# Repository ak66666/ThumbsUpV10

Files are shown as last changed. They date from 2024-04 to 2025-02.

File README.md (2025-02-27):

# ThumbsUp! v10 RP2040 Kailh Choc

Multilevel 44/46 Key Contoured Keyboard.
2- or 3-key Thumb Cluster.

* RP2040 is soldered on the board itself.
* Supports ProGlide Cirque touchpad.
* Hot swap sockets for switches.
* USB-C connector.
* Compact key spacing (18x17), large MX-size caps won't fit.
* Some keys on the lower PCB are tucked under the middle board to bring the index and middle fingers closer. That limits the choice of the key caps even more, only low profile would fit.

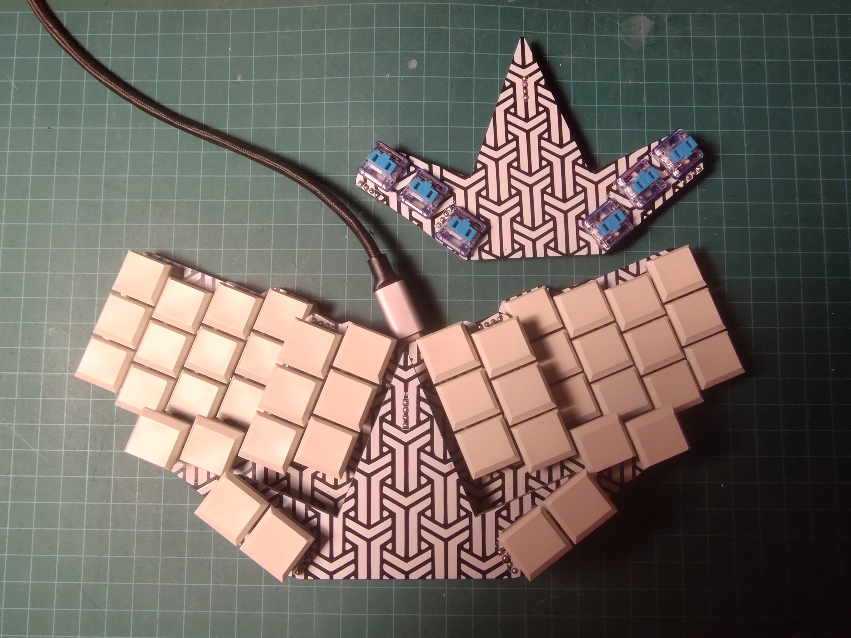
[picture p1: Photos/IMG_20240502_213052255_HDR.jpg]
Main view

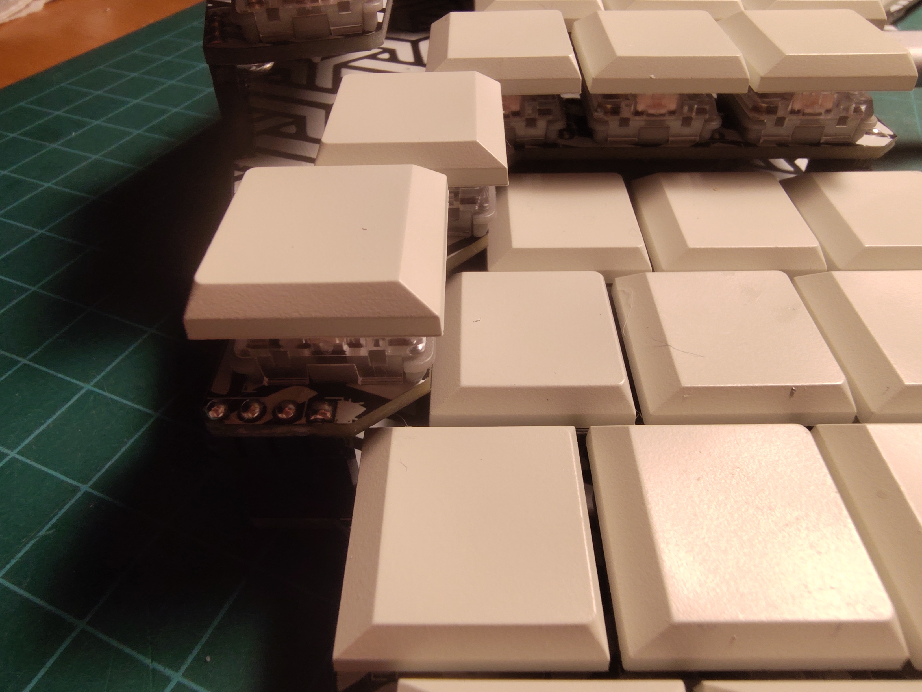
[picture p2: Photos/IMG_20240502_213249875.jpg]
Some keys are tucked under the middle PCB


Other pictures in Photos folder.

# Firmware

Please refer to this article:
https://thumbsupkeyboards.blogspot.com/2024/02/source-files-and-default-firmware.html

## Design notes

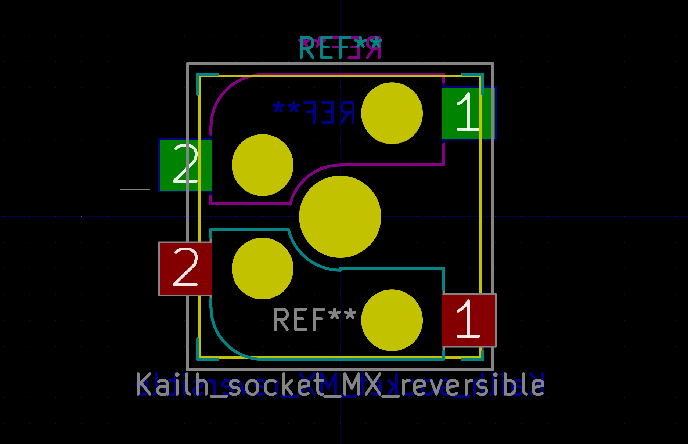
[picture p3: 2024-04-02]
keyswitches.pretty-master/images/Kailh_socket_MX_reversible_platemount.png

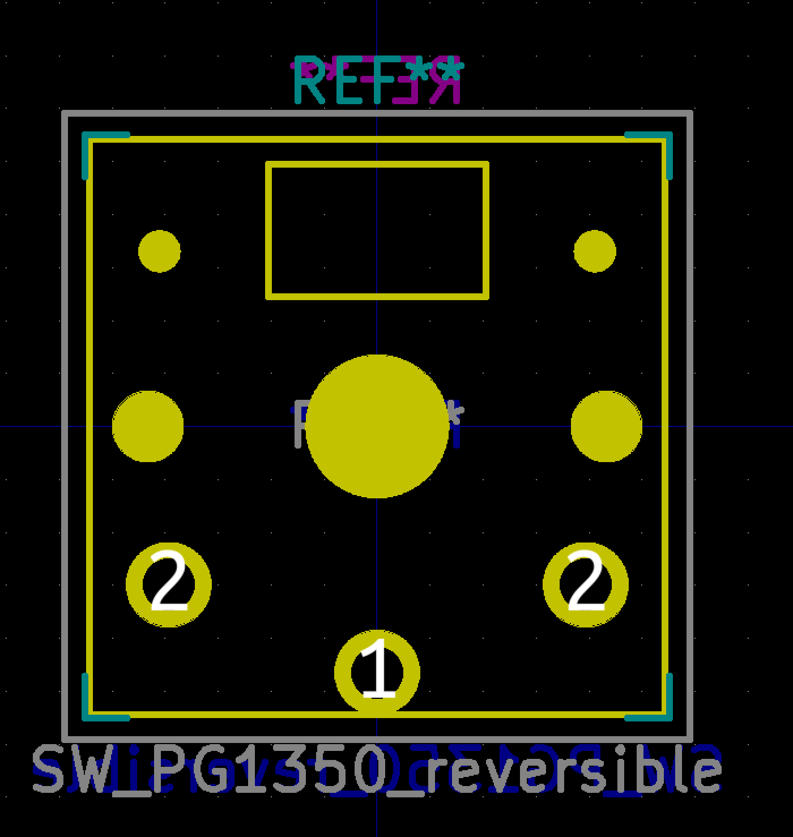
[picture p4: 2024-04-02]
keyswitches.pretty-master/images/SW_PG1350_reversible.png

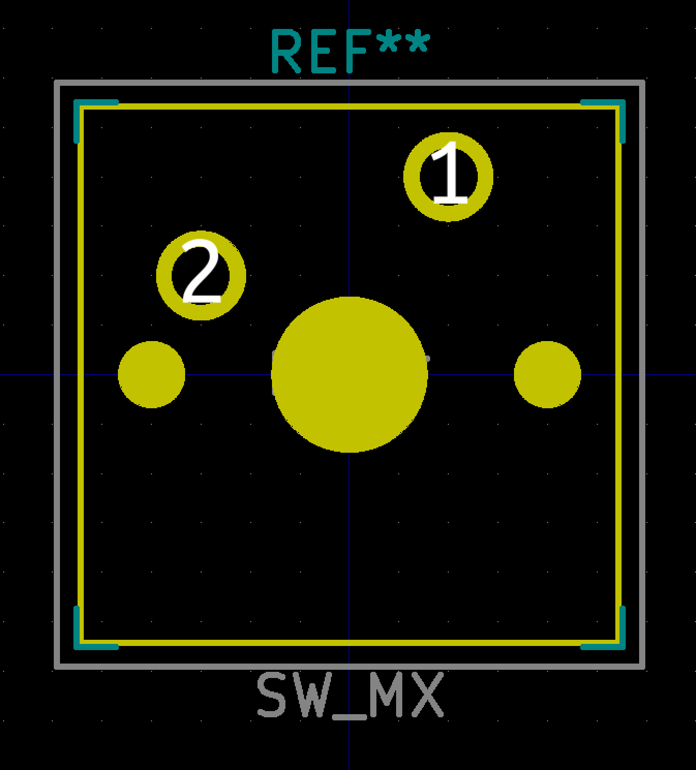
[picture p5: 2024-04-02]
keyswitches.pretty-master/images/SW_MX.png

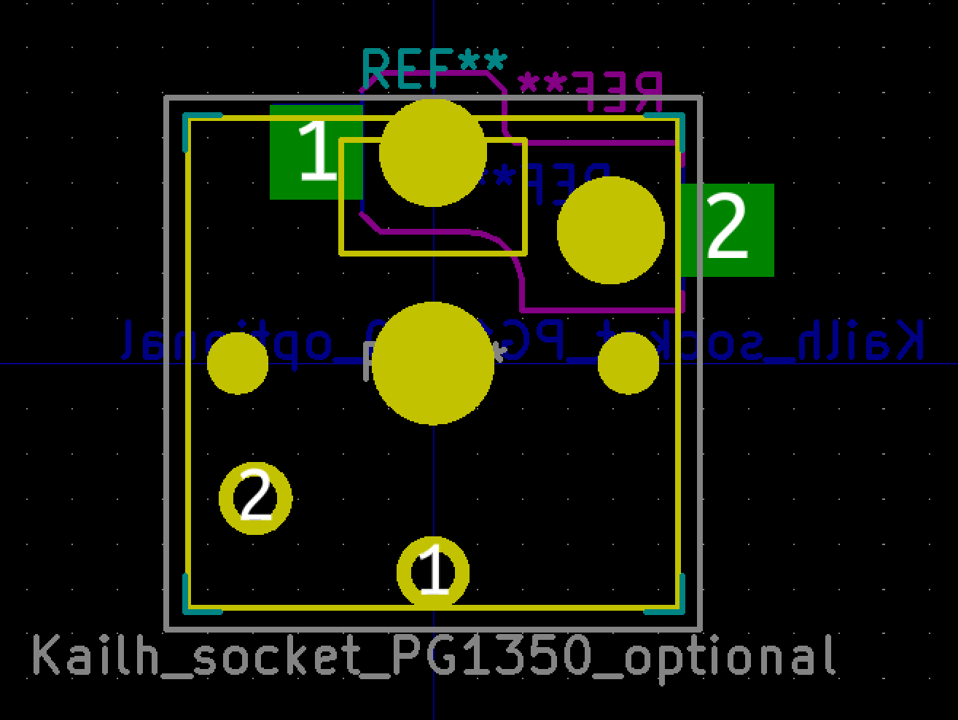
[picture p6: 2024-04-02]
keyswitches.pretty-master/images/Kailh_socket_PG1350_optional.png

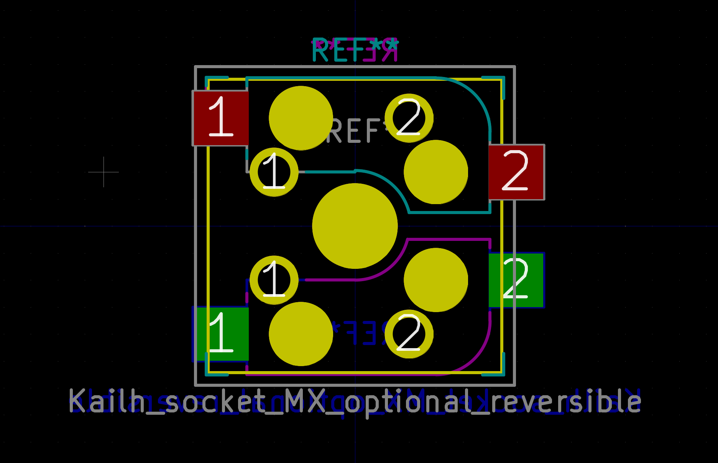
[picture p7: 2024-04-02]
keyswitches.pretty-master/images/Kailh_socket_MX_optional_reversible_platemount.png

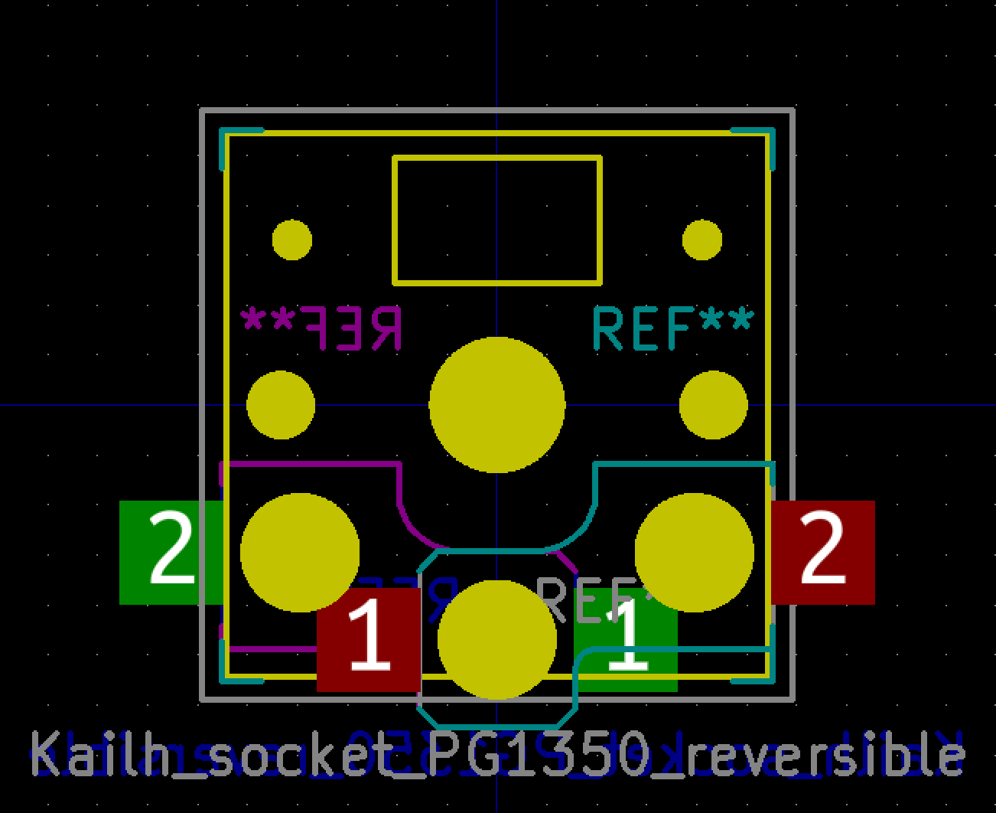
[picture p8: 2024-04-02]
keyswitches.pretty-master/images/Kailh_socket_PG1350_reversible.png

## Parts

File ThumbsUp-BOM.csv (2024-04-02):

Id | Designator | Package | Quantity | Designation | Supplier and ref
1 | R9,R8 | R_0805_2012Metric | 2 | 5.1k
2 | J32 | USB_C_Receptacle_Palconn_UTC16-G | 1 | USB_C_Receptacle_USB2.0
3 | RUN1,BOOTSEL1 | TL1016AAF220QG | 2 | TL1016AAF220QG
4 | IC1 | QFN40P700X700X90-57N-D | 1 | RP2040
5 | D25,D44,D43,D42,D41,D40,D39,D38,D37,D36,D35,D34,D33,D32,D31,D30,D29,D28,D27,D26,D24,D23,D22,D21,D20,D19,D18,D17,D16,D15,D14,D13,D12,D11,D10,D9,D8,D7,D6,D5,D4,D3,D2,D1 | D_SOD-123 | 44 | D_Small
6 | Y1 | HC%2f49US-(AT49)_1 | 1 | ABLS-12.000MHZ-B4-T
7 | R3 | R_0805_2012Metric | 1 | 10k
8 | IC2 | SOIC127P790X216-8N | 1 | W25Q128JVSIM
9 | C9,C11 | C_0805_2012Metric | 2 | 10uF
10 | C7,C6,C2,C1,C17,C16,C15,C14,C13,C10 | C_0805_2012Metric | 10 | 0.1uF
11 | C5,C4 | C_0805_2012Metric | 2 | 27pF
12 | C3,C12 | C_0805_2012Metric | 2 | 1uF
13 | U1 | SOT-223-3_TabPin2 | 1 | NCP1117-3.3_SOT223
14 | R7 | R_0805_2012Metric | 1 | DNF
15 | R6 | R_0805_2012Metric | 1 | 1k
16 | R5,R4 | R_0805_2012Metric | 2 | 4.7k
17 | R2,R1 | R_0805_2012Metric | 2 | 27.4
18 | F1 | Fuse_1206_3216Metric | 1 | Polyfuse
19 | J27,J24,J25,J26,J6,J4 | PinHeader_1x04_P2.54mm_Vertical | 6 | Conn_01x04_Male
20 | J18,J10,J14 | PinHeader_1x04_P2.54mm_Vertical | 3 | Raiser_Male
21 | MX38 | Kailh_socket_PG1350_optional | 1 | SwMENU
22 | MX27 | Kailh_socket_PG1350_optional | 1 | SwU
23 | MX28 | Kailh_socket_PG1350_optional | 1 | SwJ
24 | MX29 | Kailh_socket_PG1350_optional | 1 | SwM
25 | MX34 | Kailh_socket_PG1350_optional | 1 | SwRALT
26 | J20,J21,J22,J23 | PinSocket_1x04_P2.54mm_Vertical | 4 | Conn_01x04_Female
27 | MX15 | Kailh_socket_PG1350_optional | 1 | SwR
28 | MX24 | Kailh_socket_PG1350_optional | 1 | SwH
29 | MX10 | Kailh_socket_PG1350_optional | 1 | SwLWIN
30 | MX14 | Kailh_socket_PG1350_optional | 1 | SwLALT
31 | MX17 | Kailh_socket_PG1350_optional | 1 | SwV
32 | MX25 | Kailh_socket_PG1350_optional | 1 | SwN
33 | MX19 | Kailh_socket_PG1350_optional | 1 | SwT
34 | MX21 | Kailh_socket_PG1350_optional | 1 | SwB
35 | MX20 | Kailh_socket_PG1350_optional | 1 | SwG
36 | MX23 | Kailh_socket_PG1350_optional | 1 | SwY
37 | MX16 | Kailh_socket_PG1350_optional | 1 | SwF
38 | J15,J11 | PinSocket_1x04_P2.54mm_Vertical | 2 | Raiser_Female

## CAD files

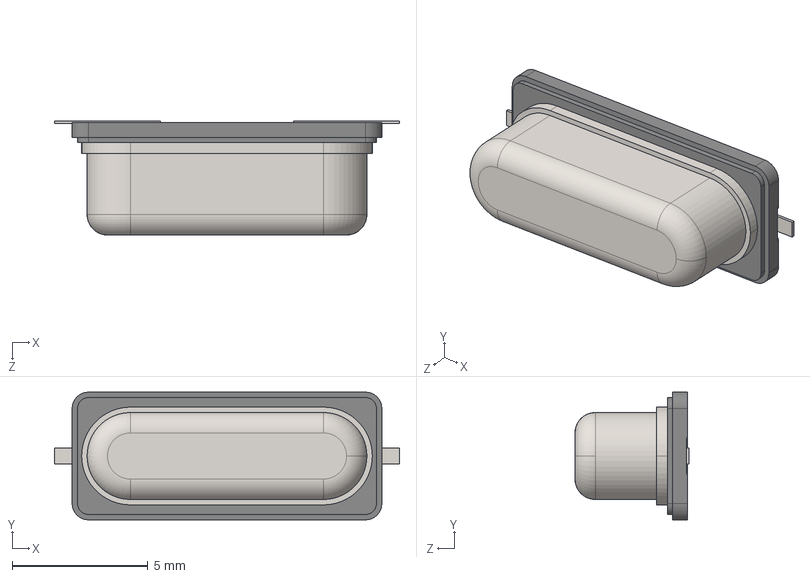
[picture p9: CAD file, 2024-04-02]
ABLS-12.000MHZ-B4-T/3D/ABLS-12.000MHZ-B4-T.stp
12.7 x 4.70 x 4.20 mm

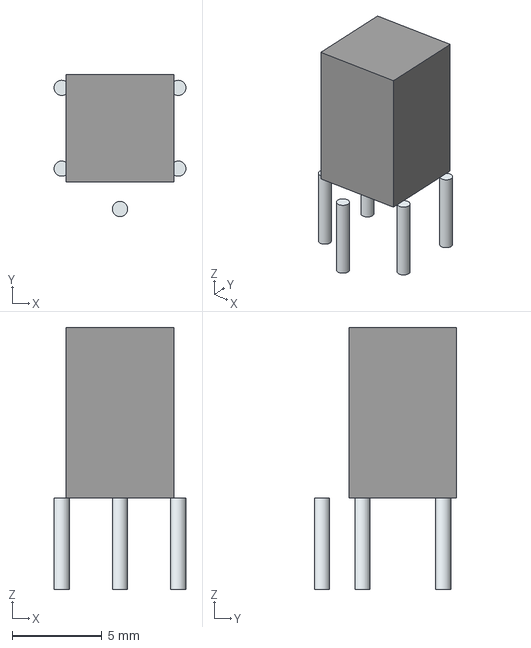
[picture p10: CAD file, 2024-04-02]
LIB_BUTT-4/BUTT-4/3D/BUTT-4.stp
7.35 x 7.92 x 14.6 mm
Leads x 5

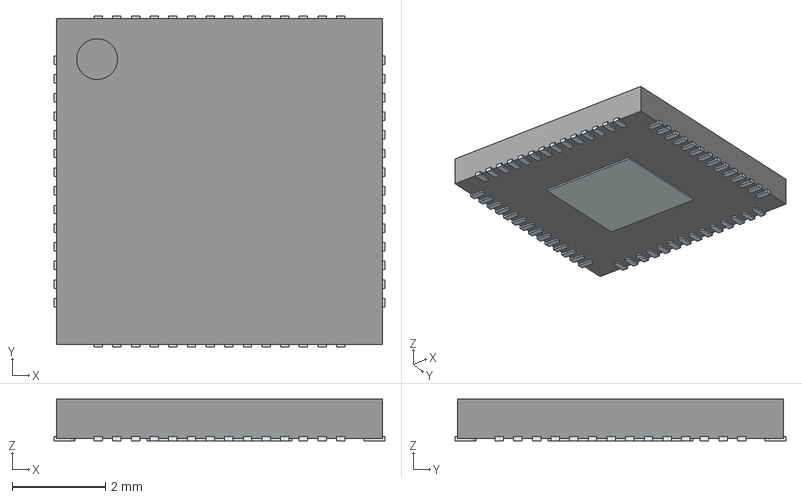
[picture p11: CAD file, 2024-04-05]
RP2040/3D/RP2040.stp
7.10 x 7.10 x 0.9 mm
ThermalPin
PinsArrayLR
PinsArrayTB

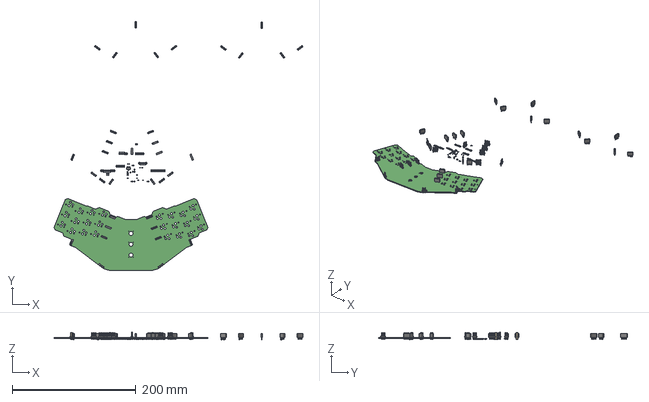
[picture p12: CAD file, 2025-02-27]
ThumbsUp.step
401.7 x 401.0 x 11.9 mm

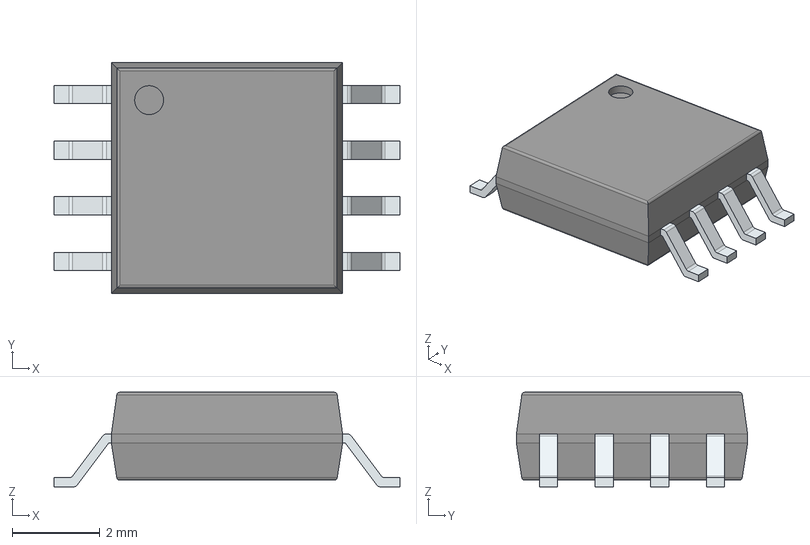
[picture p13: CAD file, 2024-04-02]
W25Q128JVSIM/3D/W25Q128JVSIM.stp
7.90 x 5.28 x 2.16 mm
PinsArrayLR

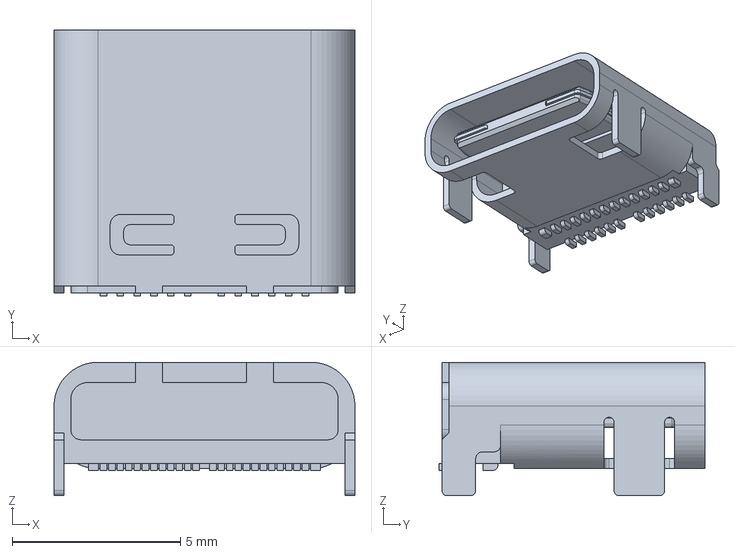
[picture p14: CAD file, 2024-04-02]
105450-0101/3D/105450-0101.stp
8.94 x 7.90 x 3.96 mm

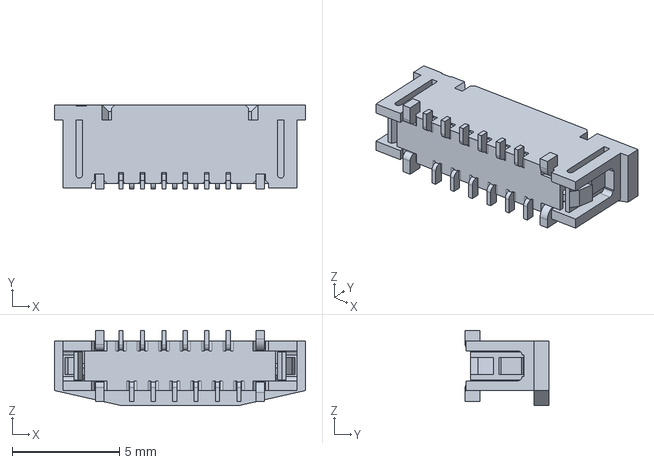
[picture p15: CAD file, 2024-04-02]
Molex 52559-1233/52559-1233/3D/52559-1233.stp
11.7 x 3.90 x 3.50 mm

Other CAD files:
ABLS-12.000MHZ-B4-T/Allegro/hc_49us-_at49__1.psm
ABLS-12.000MHZ-B4-T/DEHDL/abls_12.000mhz_b4_t/chips/chips.prt
EVQ-P7B01P/Allegro/evqp7b01p.psm
EVQ-P7B01P/DEHDL/evq_p7b01p/chips/chips.prt
LIB_BUTT-4/BUTT-4/Allegro/butt4.psm
LIB_BUTT-4/BUTT-4/DEHDL/butt_4/chips/chips.prt
Molex 52559-1233/52559-1233/Allegro/525591233.psm
Molex 52559-1233/52559-1233/DEHDL/52559_1233/chips/chips.prt
RP2040/Allegro/qfn40p700x700x90-57n-d.psm
RP2040/DEHDL/rp2040/chips/chips.prt
TL1016AAF220QG/Allegro/tl1016aaf220qg.psm
TL1016AAF220QG/DEHDL/tl1016aaf220qg/chips/chips.prt
W25Q128JVSIM/Allegro/soic127p790x216-8n.psm
W25Q128JVSIM/DEHDL/w25q128jvsim/chips/chips.prt

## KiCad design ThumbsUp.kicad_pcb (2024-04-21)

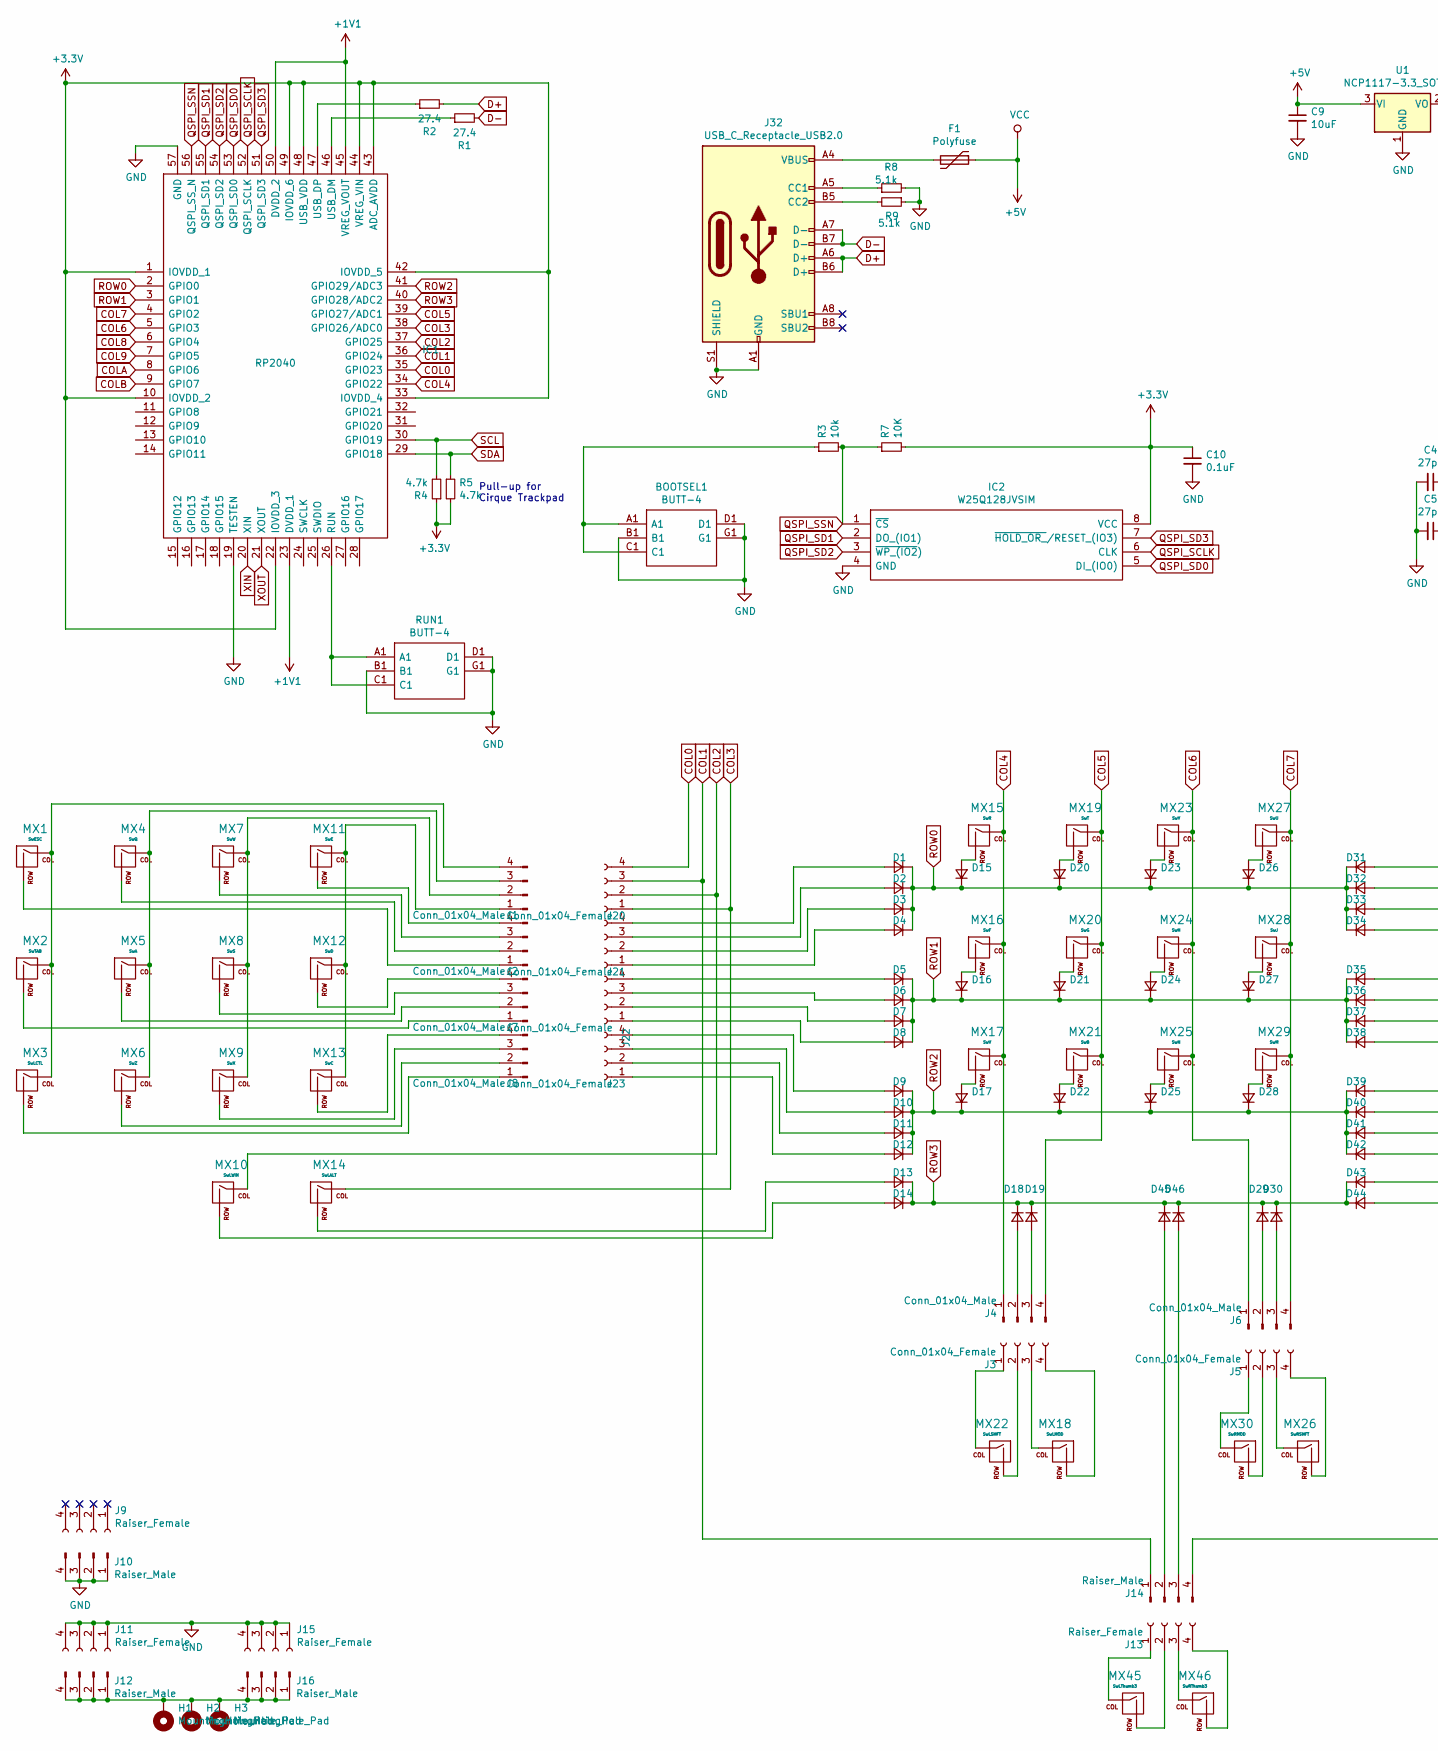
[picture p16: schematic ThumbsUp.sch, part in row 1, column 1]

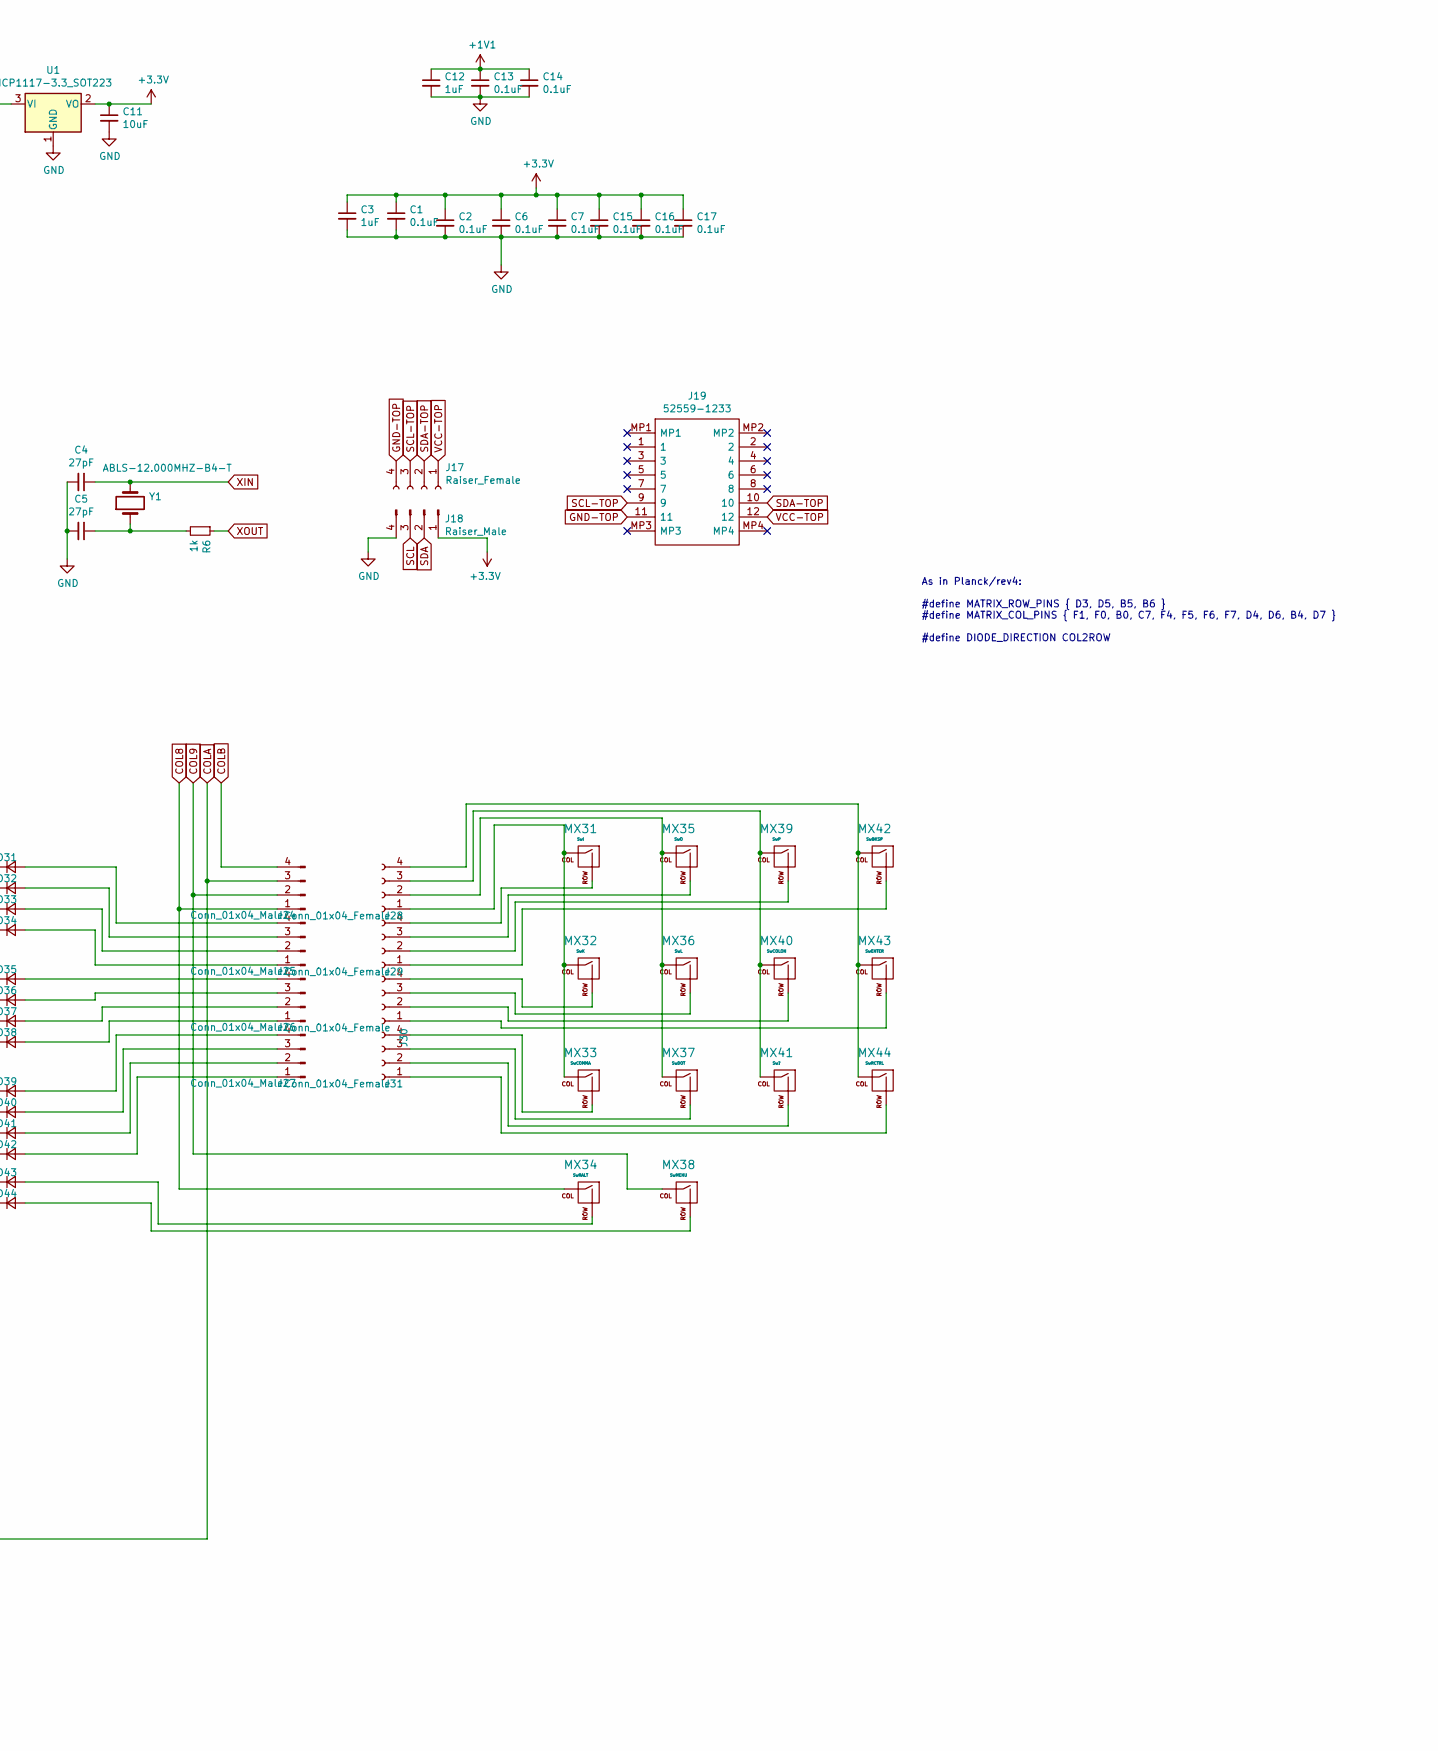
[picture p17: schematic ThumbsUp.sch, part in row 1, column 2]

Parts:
BOOTSEL1: BUTT-4; BUTT4; Manufacturer_Part_Number BUTT-4; Mouser Part Number 992-BUTT-4
C1, C2, C6, C7, C10, C13, C14, C15, C16, C17: 0.1uF; C_0805_2012Metric
C3, C12: 1uF; C_0805_2012Metric
C4, C5: 27pF; C_0805_2012Metric
C9, C11: 10uF; C_0805_2012Metric
D1, D2, D3, D4, D5, D6, D7, D8, D9, D10, D11, D12, D13, D14, D15, D16, D17, D18, D19, D20, D21, D22, D23, D24, D25, D26, D27, D28, D29, D30, D31, D32, D33, D34, D35, D36, D37, D38, D39, D40, D41, D42, D43, D44, D45, D46: D_Small; D_SOD-123
F1: Polyfuse; Fuse_1206_3216Metric
H1, H2, H3: MountingHole_Pad; MountingHole_6.4mm_M6_Pad_Via
IC1: RP2040; QFN40P700X700X90-57N-D; Manufacturer_Part_Number RP2040
IC2: W25Q128JVSIM; SOIC127P790X216-8N; Manufacturer_Part_Number W25Q128JVSIM; Mouser Part Number 454-W25Q128JVSIM
J1, J2, J4, J6, J7, J8, J24, J25, J26, J27: Conn_01x04_Male; PinHeader_1x04_P2.54mm_Vertical
J3, J5, J20, J21, J22, J23, J28, J29, J30, J31: Conn_01x04_Female; PinSocket_1x04_P2.54mm_Vertical
J9, J11, J13, J15, J17: Raiser_Female; PinSocket_1x04_P2.54mm_Vertical
J10, J12, J14, J16, J18: Raiser_Male; PinHeader_1x04_P2.54mm_Vertical
J19: 52559-1233; 525591233; Mouser Part Number 538-52559-1233
J32: USB_C_Receptacle_USB2.0; USB_C_Receptacle_Palconn_UTC16-G
MX1: SwESC; Kailh_socket_PG1350
MX2: SwTAB; Kailh_socket_PG1350
MX3: SwLCTL; Kailh_socket_PG1350
MX4: SwQ; Kailh_socket_PG1350
MX5: SwA; Kailh_socket_PG1350
MX6: SwZ; Kailh_socket_PG1350
MX7: SwW; Kailh_socket_PG1350
MX8: SwS; Kailh_socket_PG1350
MX9: SwX; Kailh_socket_PG1350
MX10: SwLWIN; Kailh_socket_PG1350
MX11: SwE; Kailh_socket_PG1350
MX12: SwD; Kailh_socket_PG1350
MX13: SwC; Kailh_socket_PG1350
MX14: SwLALT; Kailh_socket_PG1350
MX15: SwR; Kailh_socket_PG1350
MX16: SwF; Kailh_socket_PG1350
MX17: SwV; Kailh_socket_PG1350
MX18: SwLMOD; Kailh_socket_PG1350
MX19: SwT; Kailh_socket_PG1350
MX20: SwG; Kailh_socket_PG1350
MX21: SwB; Kailh_socket_PG1350
MX22: SwLSHFT; Kailh_socket_PG1350
MX23: SwY; Kailh_socket_PG1350
MX24: SwH; Kailh_socket_PG1350
MX25: SwN; Kailh_socket_PG1350
MX26: SwRSHFT; Kailh_socket_PG1350
MX27: SwU; Kailh_socket_PG1350
MX28: SwJ; Kailh_socket_PG1350
MX29: SwM; Kailh_socket_PG1350
MX30: SwRMOD; Kailh_socket_PG1350
MX31: SwI; Kailh_socket_PG1350
MX32: SwK; Kailh_socket_PG1350
MX33: SwCOMMA; Kailh_socket_PG1350
MX34: SwRALT; Kailh_socket_PG1350
MX35: SwO; Kailh_socket_PG1350
MX36: SwL; Kailh_socket_PG1350
MX37: SwDOT; Kailh_socket_PG1350
MX38: SwMENU; Kailh_socket_PG1350
MX39: SwP; Kailh_socket_PG1350
MX40: SwCOLON; Kailh_socket_PG1350
MX41: Sw?; Kailh_socket_PG1350
MX42: SwBKSP; Kailh_socket_PG1350
MX43: SwENTER; Kailh_socket_PG1350
MX44: SwRCTRL; Kailh_socket_PG1350
MX45: SwLThumb3; Kailh_socket_PG1350
MX46: SwRThumb3; Kailh_socket_PG1350
R1, R2: 27.4; R_0805_2012Metric
R3: 10k; R_0805_2012Metric
R4, R5: 4.7k; R_0805_2012Metric
R6: 1k; R_0805_2012Metric
R7: 10K; R_0805_2012Metric
R8, R9: 5.1k; R_0805_2012Metric
RUN1: BUTT-4; BUTT4; Manufacturer_Part_Number BUTT-4; Mouser Part Number 992-BUTT-4
U1: NCP1117-3.3_SOT223; SOT-223-3_TabPin2
Y1: ABLS-12.000MHZ-B4-T; HC%2f49US-(AT49)_1

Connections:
+1V1: C12.1, C13.1, C14.1, IC1.23 (DVDD_1), IC1.45 (VREG_VOUT), IC1.50 (DVDD_2)
+3V3: C1.1, C2.1, C3.1, C6.1, C7.1, C10.1, C11.1, C15.1, C16.1, C17.1, IC1.1 (IOVDD_1), IC1.10 (IOVDD_2), IC1.22 (IOVDD_3), IC1.33 (IOVDD_4), IC1.42 (IOVDD_5), IC1.43 (ADC_AVDD), IC1.44 (VREG_VIN), IC1.48 (USB_VDD), IC1.49 (IOVDD_6), IC2.8 (VCC), J18.1, R4.1, R5.2, R7.2, U1.2 (VO)
+5V: C9.1, F1.1, U1.3 (VI)
COL0: IC1.35 (GPIO23), J20.4
COL1: IC1.36 (GPIO24), J14.1, J20.3
COL2: IC1.37 (GPIO25), J20.2, MX10.1 (COL)
COL3: IC1.38 (GPIO26/ADC0), J20.1, MX14.1 (COL)
COL4: IC1.34 (GPIO22), J4.1, MX15.1 (COL), MX16.1 (COL), MX17.1 (COL)
COL5: IC1.39 (GPIO27/ADC1), J4.4, MX19.1 (COL), MX20.1 (COL), MX21.1 (COL)
COL6: IC1.5 (GPIO3), J6.1, MX23.1 (COL), MX24.1 (COL), MX25.1 (COL)
COL7: IC1.4 (GPIO2), J6.4, MX27.1 (COL), MX28.1 (COL), MX29.1 (COL)
COL8: IC1.6 (GPIO4), J24.1, MX34.1 (COL)
COL9: IC1.7 (GPIO5), J24.2, MX38.1 (COL)
COLA: IC1.8 (GPIO6), J14.4, J24.3
COLB: IC1.9 (GPIO7), J24.4
D+: J32.A6 (D+), J32.B6 (D+), R2.2
D-: J32.A7 (D-), J32.B7 (D-), R1.2
GND: BOOTSEL1.B1, BOOTSEL1.D1, BOOTSEL1.G1, C1.2, C2.2, C3.2, C4.2, C5.2, C6.2, C7.2, C9.2, C10.2, C11.2, C12.2, C13.2, C14.2, C15.2, C16.2, C17.2, IC1.19 (TESTEN), IC1.57 (GND), IC2.4 (GND), J10.1, J10.2, J10.3, J10.4, J11.1, J11.2, J11.3, J11.4, J15.1, J15.2, J15.3, J15.4, J18.4, J32.A1 (GND), J32.A12 (GND), J32.B1 (GND), J32.B12 (GND), J32.S1 (SHIELD), R8.2, R9.1, RUN1.B1, RUN1.D1, RUN1.G1, U1.1 (GND)
GND-TOP: J17.4, J19.11; also elsewhere on the board
unnamed: BOOTSEL1.A1, BOOTSEL1.C1, R3.1
unnamed: C5.1, R6.2, Y1.1
unnamed: D1.2 (A), J21.4
unnamed: D2.2 (A), J21.3
unnamed: D3.2 (A), J21.2
unnamed: D4.2 (A), J21.1
unnamed: D5.2 (A), J22.4
unnamed: D6.2 (A), J22.3
unnamed: D7.2 (A), J22.2
unnamed: D8.2 (A), J22.1
unnamed: D9.2 (A), J23.4
unnamed: D10.2 (A), J23.3
unnamed: D11.2 (A), J23.2
unnamed: D12.2 (A), J23.1
unnamed: D13.2 (A), MX14.2 (ROW)
unnamed: D14.2 (A), MX10.2 (ROW)
unnamed: D15.2 (A), MX15.2 (ROW)
unnamed: D16.2 (A), MX16.2 (ROW)
unnamed: D17.2 (A), MX17.2 (ROW)
unnamed: D18.2 (A), J4.2
unnamed: D19.2 (A), J4.3
unnamed: D20.2 (A), MX19.2 (ROW)
unnamed: D21.2 (A), MX20.2 (ROW)
unnamed: D22.2 (A), MX21.2 (ROW)
unnamed: D23.2 (A), MX23.2 (ROW)
unnamed: D24.2 (A), MX24.2 (ROW)
unnamed: D25.2 (A), MX25.2 (ROW)
unnamed: D26.2 (A), MX27.2 (ROW)
unnamed: D27.2 (A), MX28.2 (ROW)
unnamed: D28.2 (A), MX29.2 (ROW)
unnamed: D29.2 (A), J6.2
unnamed: D30.2 (A), J6.3
unnamed: D31.2 (A), J25.4
unnamed: D32.2 (A), J25.3
unnamed: D33.2 (A), J25.2
unnamed: D34.2 (A), J25.1
unnamed: D35.2 (A), J26.4
unnamed: D36.2 (A), J26.3
unnamed: D37.2 (A), J26.2
unnamed: D38.2 (A), J26.1
unnamed: D39.2 (A), J27.4
unnamed: D40.2 (A), J27.3
unnamed: D41.2 (A), J27.2
unnamed: D42.2 (A), J27.1
unnamed: D43.2 (A), MX34.2 (ROW)
unnamed: D44.2 (A), MX38.2 (ROW)
unnamed: D45.2 (A), J14.2
unnamed: D46.2 (A), J14.3
unnamed: F1.2, J32.A4 (VBUS), J32.A9 (VBUS), J32.B4 (VBUS), J32.B9 (VBUS)
unnamed: H1.1, H2.1, H3.1, J12.1, J12.2, J12.3, J12.4, J16.1, J16.2, J16.3, J16.4
unnamed: IC1.26 (RUN), RUN1.A1, RUN1.C1
unnamed: IC1.46 (USB_DM), R1.1
unnamed: IC1.47 (USB_DP), R2.1
unnamed: J1.1, MX11.1 (COL), MX12.1 (COL), MX13.1 (COL)
unnamed: J1.2, MX7.1 (COL), MX8.1 (COL), MX9.1 (COL)
unnamed: J1.3, MX4.1 (COL), MX5.1 (COL), MX6.1 (COL)
unnamed: J1.4, MX1.1 (COL), MX2.1 (COL), MX3.1 (COL)
unnamed: J2.1, MX1.2 (ROW)
unnamed: J2.2, MX4.2 (ROW)
unnamed: J2.3, MX7.2 (ROW)
unnamed: J2.4, MX11.2 (ROW)
unnamed 80: J3.1, MX22.1 (COL); also elsewhere on the board
unnamed 81: J3.2, MX22.2 (ROW); also elsewhere on the board
unnamed 82: J3.3, MX18.1 (COL); also elsewhere on the board
unnamed 83: J3.4, MX18.2 (ROW); also elsewhere on the board
unnamed 84: J5.1, MX30.1 (COL); also elsewhere on the board
unnamed 85: J5.2, MX30.2 (ROW); also elsewhere on the board
unnamed 86: J5.3, MX26.1 (COL); also elsewhere on the board
unnamed 87: J5.4, MX26.2 (ROW); also elsewhere on the board
unnamed: J7.1, MX2.2 (ROW)
unnamed: J7.2, MX5.2 (ROW)
unnamed: J7.3, MX8.2 (ROW)
unnamed: J7.4, MX12.2 (ROW)
unnamed: J8.1, MX3.2 (ROW)
unnamed: J8.2, MX6.2 (ROW)
unnamed: J8.3, MX9.2 (ROW)
unnamed: J8.4, MX13.2 (ROW)
unnamed 96: J9.1; also elsewhere on the board
unnamed 97: J9.2; also elsewhere on the board
unnamed 98: J9.3; also elsewhere on the board
unnamed 99: J9.4; also elsewhere on the board
unnamed 100: J13.1, MX45.1 (COL); also elsewhere on the board
unnamed 101: J13.2, MX45.2 (ROW); also elsewhere on the board
unnamed 102: J13.3, MX46.1 (COL); also elsewhere on the board
unnamed 103: J13.4, MX46.2 (ROW); also elsewhere on the board
unnamed 104: J19.1; also elsewhere on the board
unnamed 105: J19.2; also elsewhere on the board
unnamed 106: J19.3; also elsewhere on the board
unnamed 107: J19.4; also elsewhere on the board
unnamed 108: J19.5; also elsewhere on the board
unnamed 109: J19.6; also elsewhere on the board
unnamed 110: J19.7; also elsewhere on the board
unnamed 111: J19.8; also elsewhere on the board
unnamed 112: J19.MP1; also elsewhere on the board
unnamed 113: J19.MP2; also elsewhere on the board
unnamed 114: J19.MP3; also elsewhere on the board
unnamed 115: J19.MP4; also elsewhere on the board
unnamed: J28.1, MX31.1 (COL), MX32.1 (COL), MX33.1 (COL)
unnamed: J28.2, MX35.1 (COL), MX36.1 (COL), MX37.1 (COL)
unnamed: J28.3, MX39.1 (COL), MX40.1 (COL), MX41.1 (COL)
unnamed: J28.4, MX42.1 (COL), MX43.1 (COL), MX44.1 (COL)
unnamed: J29.1, MX42.2 (ROW)
unnamed: J29.2, MX39.2 (ROW)
unnamed: J29.3, MX35.2 (ROW)
unnamed: J29.4, MX31.2 (ROW)
unnamed: J30.1, MX43.2 (ROW)
unnamed: J30.2, MX40.2 (ROW)
unnamed: J30.3, MX36.2 (ROW)
unnamed: J30.4, MX32.2 (ROW)
unnamed: J31.1, MX44.2 (ROW)
unnamed: J31.2, MX41.2 (ROW)
unnamed: J31.3, MX37.2 (ROW)
unnamed: J31.4, MX33.2 (ROW)
unnamed: J32.A5 (CC1), R8.1
unnamed: J32.B5 (CC2), R9.2
QSPI_SCLK: IC1.52 (QSPI_SCLK), IC2.6 (CLK)
QSPI_SD0: IC1.53 (QSPI_SD0), IC2.5 (DI_(IO0))
QSPI_SD1: IC1.55 (QSPI_SD1), IC2.2 (DO_(IO1))
QSPI_SD2: IC1.54 (QSPI_SD2), IC2.3 (~WP_(IO2))
QSPI_SD3: IC1.51 (QSPI_SD3), IC2.7 (~HOLD_OR_~/RESET_(IO3))
QSPI_SSN: IC1.56 (QSPI_SS_N), IC2.1 (~CS), R3.2, R7.1
ROW0: D1.1 (K), D2.1 (K), D3.1 (K), D4.1 (K), D15.1 (K), D20.1 (K), D23.1 (K), D26.1 (K), D31.1 (K), D32.1 (K), D33.1 (K), D34.1 (K), IC1.2 (GPIO0)
ROW1: D5.1 (K), D6.1 (K), D7.1 (K), D8.1 (K), D16.1 (K), D21.1 (K), D24.1 (K), D27.1 (K), D35.1 (K), D36.1 (K), D37.1 (K), D38.1 (K), IC1.3 (GPIO1)
ROW2: D9.1 (K), D10.1 (K), D11.1 (K), D12.1 (K), D17.1 (K), D22.1 (K), D25.1 (K), D28.1 (K), D39.1 (K), D40.1 (K), D41.1 (K), D42.1 (K), IC1.41 (GPIO29/ADC3)
ROW3: D13.1 (K), D14.1 (K), D18.1 (K), D19.1 (K), D29.1 (K), D30.1 (K), D43.1 (K), D44.1 (K), D45.1 (K), D46.1 (K), IC1.40 (GPIO28/ADC2)
SCL: IC1.30 (GPIO19), J18.3, R4.2
SCL-TOP: J17.3, J19.9; also elsewhere on the board
SDA: IC1.29 (GPIO18), J18.2, R5.1
SDA-TOP: J17.2, J19.10; also elsewhere on the board
VCC-TOP: J17.1, J19.12; also elsewhere on the board
XIN: C4.1, IC1.20 (XIN), Y1.2
XOUT: IC1.21 (XOUT), R6.1

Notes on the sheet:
As in Planck/rev4: #define MATRIX_ROW_PINS { D3, D5, B5, B6 } #define MATRIX_COL_PINS { F1, F0, B0, C7, F4, F5, F6, F7, D4, D6, B4, D7 } #define DIODE_DIRECTION COL2ROW
Pull-up for Cirque Trackpad

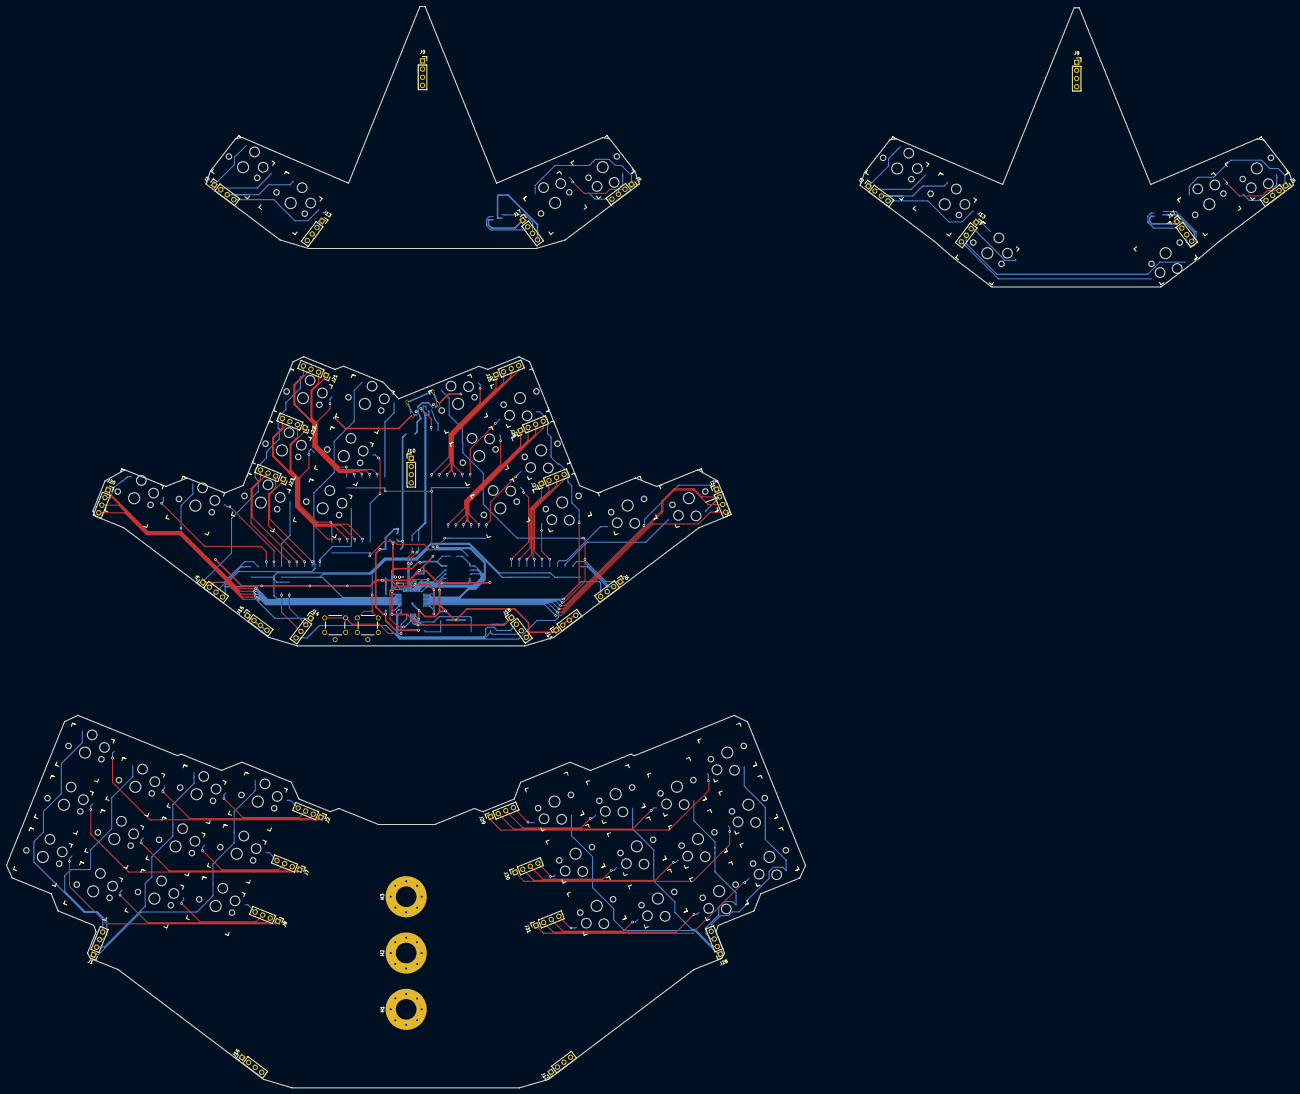
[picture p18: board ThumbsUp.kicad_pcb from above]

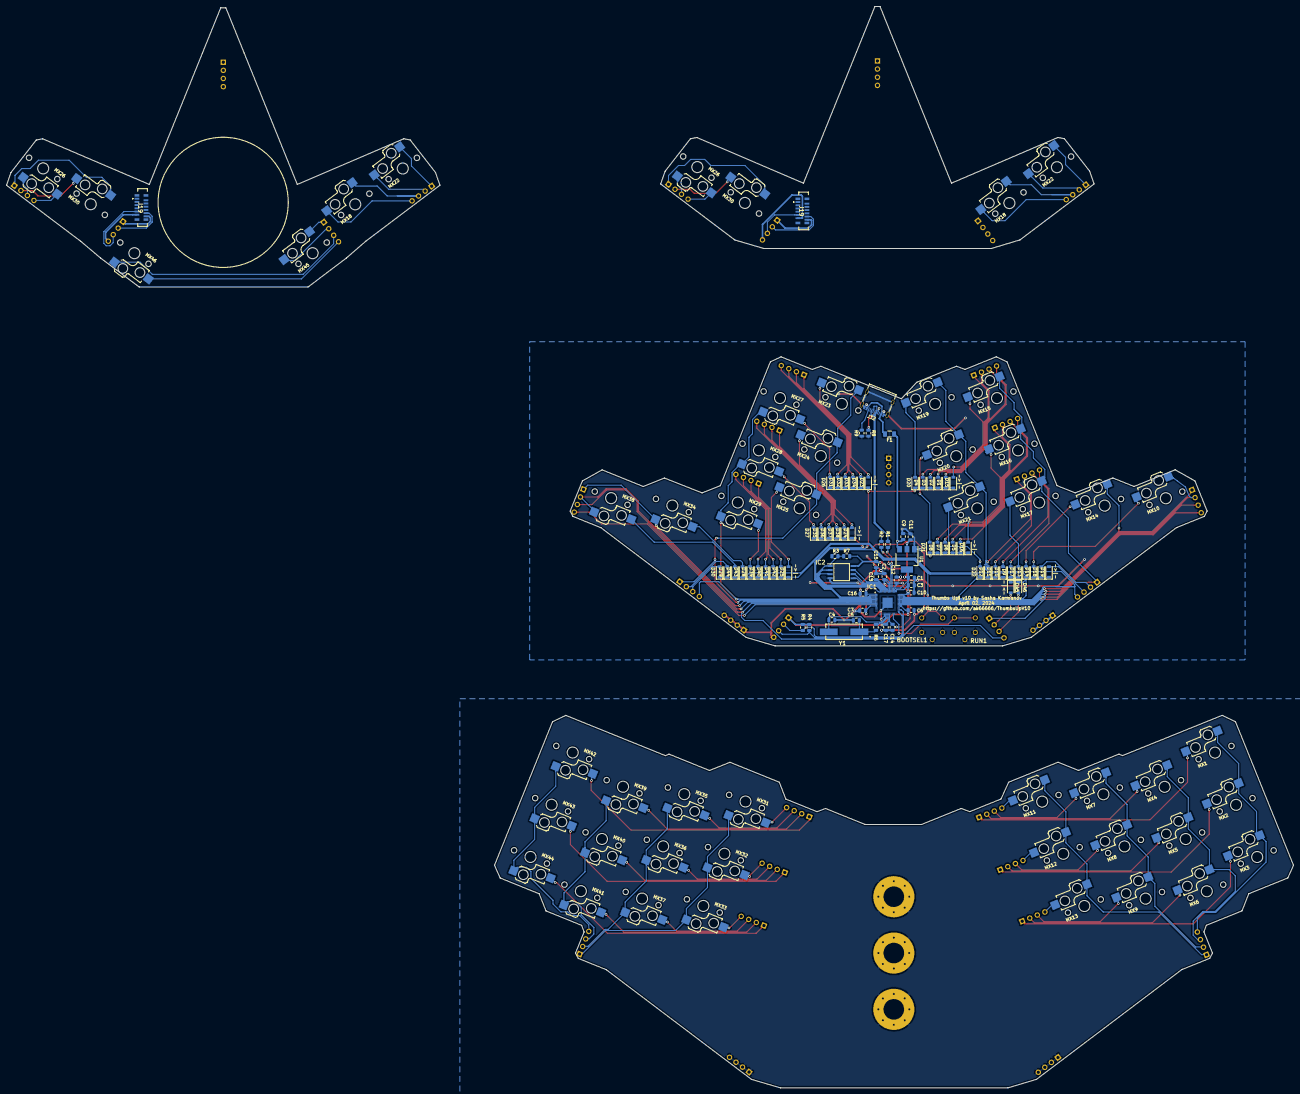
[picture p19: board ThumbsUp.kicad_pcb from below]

Board: 2 copper layers, 400.0 x 336.1 mm, 169 parts (79 on the bottom side), 151 nets.

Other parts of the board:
J3#2, J5#2: Conn_01x04_Female; PinSocket_1x04_P2.54mm_Vertical
J9#2, J13#2, J17#2: Raiser_Female; PinSocket_1x04_P2.54mm_Vertical
J19#2: 52559-1233; 525591233
MX18#2: SwLMOD; Kailh_socket_PG1350
MX22#2: SwLSHFT; Kailh_socket_PG1350
MX26#2: SwRSHFT; Kailh_socket_PG1350
MX30#2: SwRMOD; Kailh_socket_PG1350

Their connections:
GND-TOP: J17#2.4, J19#2.11; also elsewhere on the board
unnamed 80: J3#2.1, MX22#2.1; also elsewhere on the board
unnamed 81: J3#2.2, MX22#2.2; also elsewhere on the board
unnamed 82: J3#2.3, MX18#2.1; also elsewhere on the board
unnamed 83: J3#2.4, MX18#2.2; also elsewhere on the board
unnamed 84: J5#2.1, MX30#2.1; also elsewhere on the board
unnamed 85: J5#2.2, MX30#2.2; also elsewhere on the board
unnamed 86: J5#2.3, MX26#2.1; also elsewhere on the board
unnamed 87: J5#2.4, MX26#2.2; also elsewhere on the board
unnamed 96: J9#2.1; also elsewhere on the board
unnamed 97: J9#2.2; also elsewhere on the board
unnamed 98: J9#2.3; also elsewhere on the board
unnamed 99: J9#2.4; also elsewhere on the board
unnamed 100: J13#2.1; also elsewhere on the board
unnamed 101: J13#2.2; also elsewhere on the board
unnamed 102: J13#2.3; also elsewhere on the board
unnamed 103: J13#2.4; also elsewhere on the board
unnamed 104: J19#2.1; also elsewhere on the board
unnamed 105: J19#2.2; also elsewhere on the board
unnamed 106: J19#2.3; also elsewhere on the board
unnamed 107: J19#2.4; also elsewhere on the board
unnamed 108: J19#2.5; also elsewhere on the board
unnamed 109: J19#2.6; also elsewhere on the board
unnamed 110: J19#2.7; also elsewhere on the board
unnamed 111: J19#2.8; also elsewhere on the board
unnamed 112: J19#2.MP1; also elsewhere on the board
unnamed 113: J19#2.MP2; also elsewhere on the board
unnamed 114: J19#2.MP3; also elsewhere on the board
unnamed 115: J19#2.MP4; also elsewhere on the board
SCL-TOP: J17#2.3, J19#2.9; also elsewhere on the board
SDA-TOP: J17#2.2, J19#2.10; also elsewhere on the board
VCC-TOP: J17#2.1, J19#2.12; also elsewhere on the board

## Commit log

2024-04-02 ThumbsUp! v10 started
    [105450-0101.stp, 52559-1233.stp, 525591233.psm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]
2024-04-05 ThumbsUp! v10 moved the keys around
    [EDI2CAP.CFG, QFN40P700X700X90-57N-D.PcbLib, RP2040.SchLib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]
2024-04-09 Redefined boundaries of the middle PCB.
    [ThumbsUp.kicad_pcb]
2024-04-12 Redefined boundaries of the lower PCB.
    [ThumbsUp.kicad_pcb]
2024-04-20 Traced bottom PCB.
    [ThumbsUp.kicad_pcb, ThumbsUp.sch]
2024-04-21 Traced middle PCB.
    [ThumbsUp.kicad_pcb, ThumbsUp.sch]
2024-04-21 Traced top PCB, tweaked tracks here and there.
    [ThumbsUp.kicad_pcb]
2024-04-25 Added silkscreens.
2024-04-25 Added Gerbers.
    [ThumbsUp-B_Cu.gbr, ThumbsUp-B_Mask.gbr, ThumbsUp-B_Paste.gbr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]
2024-04-25 Fixed BOM.
    [v10-L2-BOM.xlsx]
2025-02-27 ThumbsUp v10: Added photos, updated description.
    [ThumbsUp.step]
